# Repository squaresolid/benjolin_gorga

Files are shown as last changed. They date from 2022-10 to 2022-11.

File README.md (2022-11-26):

# benjolin_gorga
A tribute to Rob Hordijk (RIP)

As I was taking care of my wife at the hospital, I decided to redesign Forestcaver's Benjolin https://github.com/forestcaver/Benjolin
As I was finishing this, Rob Hordijk passed away and I would like to dedicate this to him.
The board come with several changes, which is: 
- 1206 components instead of 0603 which allows a much friendlier hand soldering
- DIP package for SSM2164 as in Indonesia it's pretty hard to find SMD components
- Gorga Graphics for Panel (Panel size is still as eurorack standard so no efficient cost production can be made)
- 100mm x 78mm circuit board redesign which allows a much cheaper PCB production.
- Optionable switch footprints, as the small switch is quite difficult to find in Indonesia
- Rearranged the layout a bit so all the knobs is on the right side

A eurorack version 1.6 of Rob Hordijk's Benjolin with 100mm x 78mm which significantly reduce the cost of printing PCB. The panel still on eurorack standard size though, so no cost reduction there. The panel design is enhanced with Batak's Gorga (Indonesian tribe from Sumatra) drawings.

All Kicad file provided is using Kicad 6

== Panel design ==
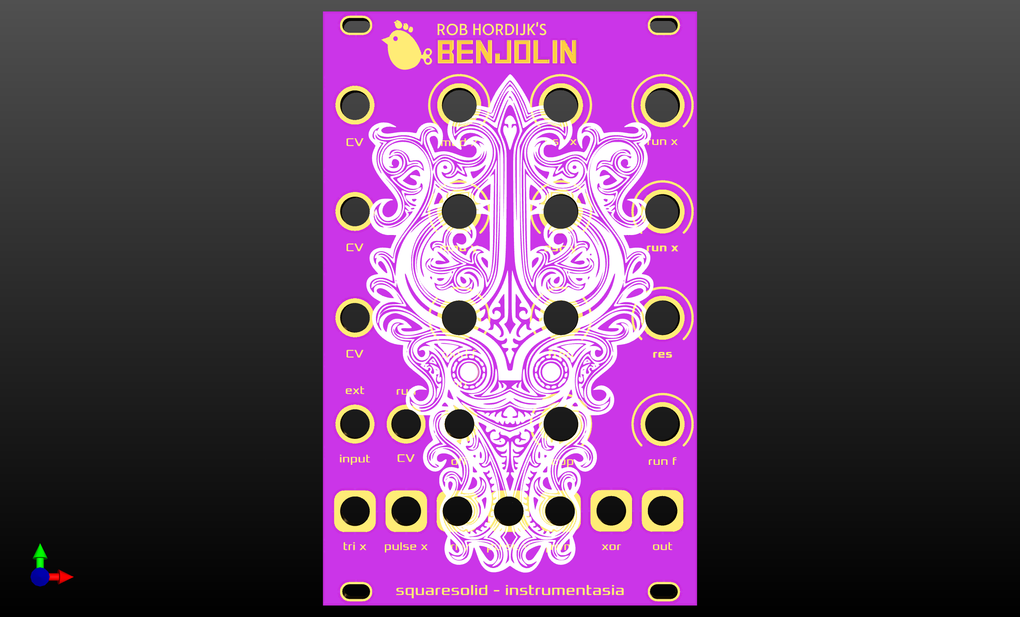
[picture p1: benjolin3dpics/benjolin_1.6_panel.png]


== PCB design ==
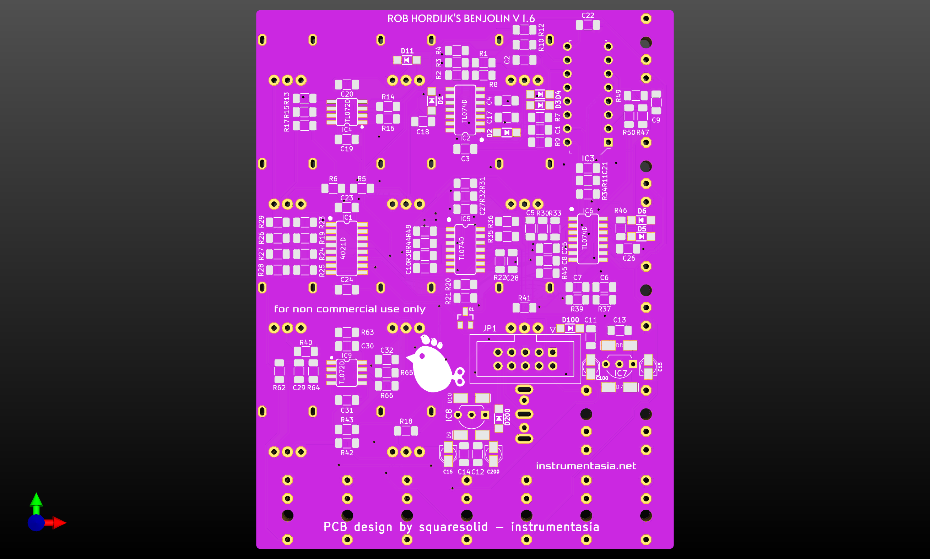
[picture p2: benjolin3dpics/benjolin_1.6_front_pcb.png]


== Build design ==
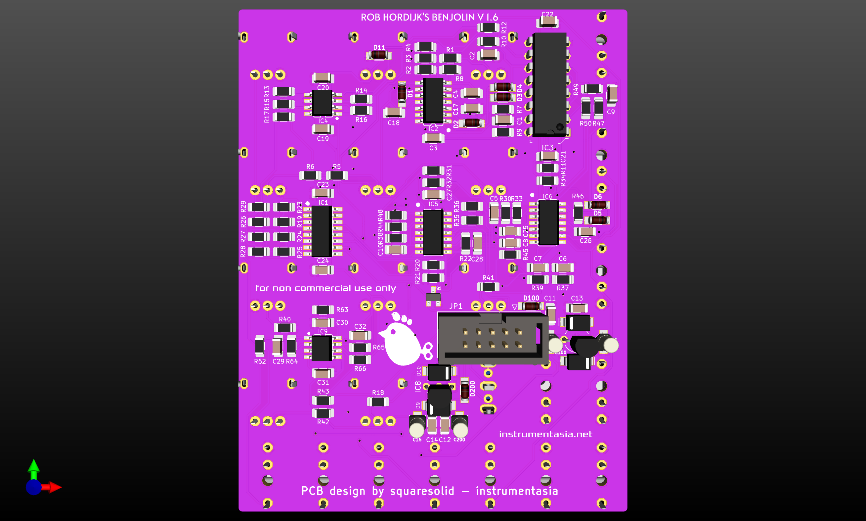
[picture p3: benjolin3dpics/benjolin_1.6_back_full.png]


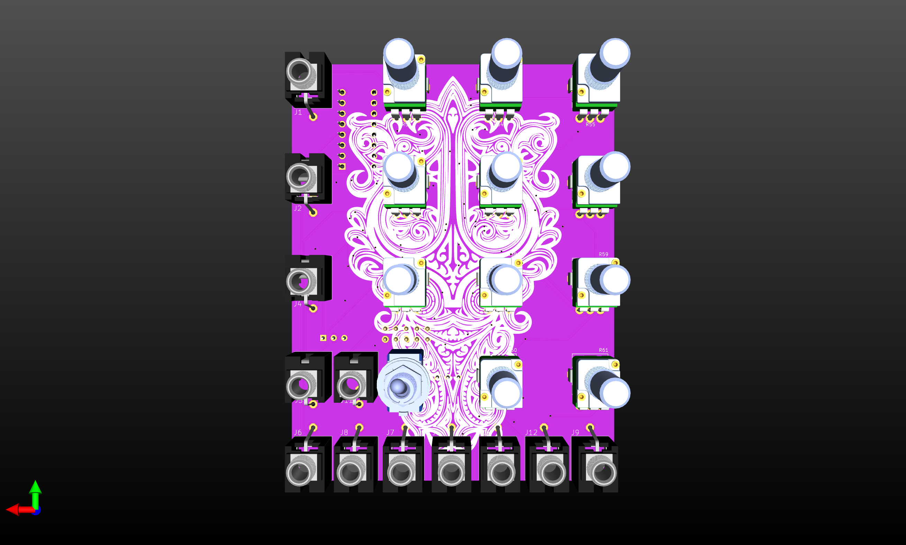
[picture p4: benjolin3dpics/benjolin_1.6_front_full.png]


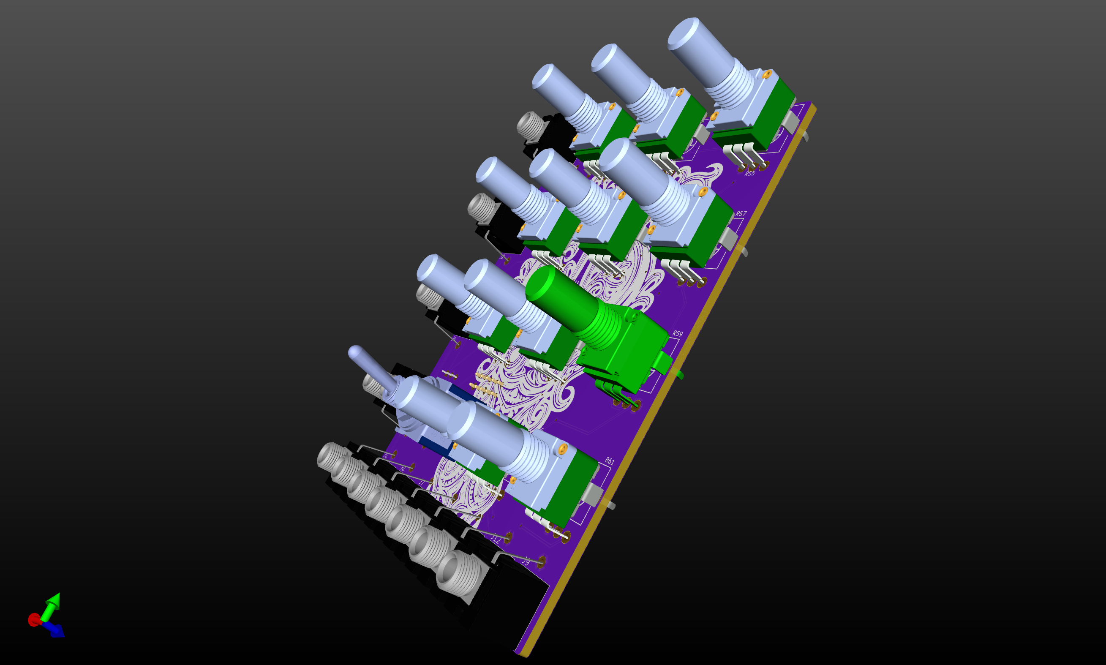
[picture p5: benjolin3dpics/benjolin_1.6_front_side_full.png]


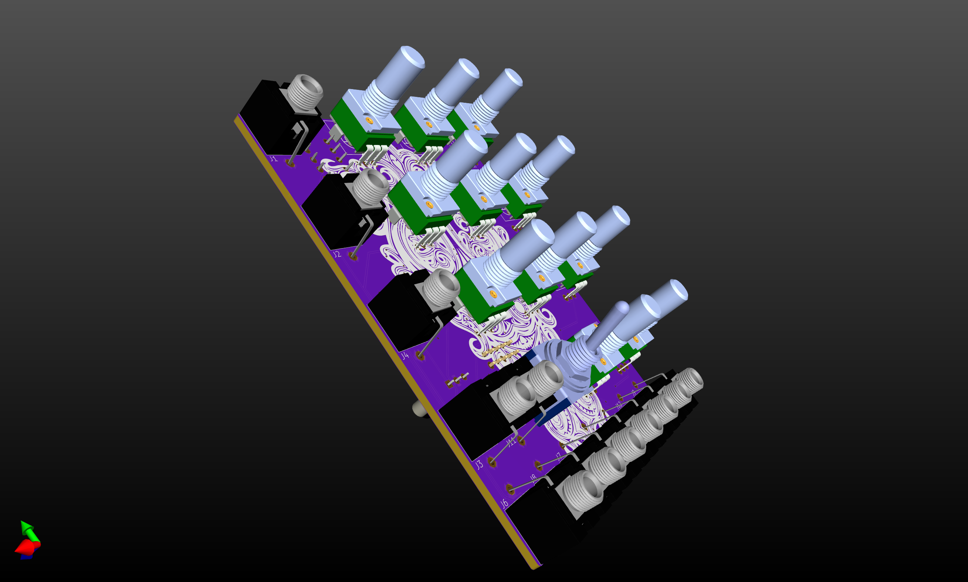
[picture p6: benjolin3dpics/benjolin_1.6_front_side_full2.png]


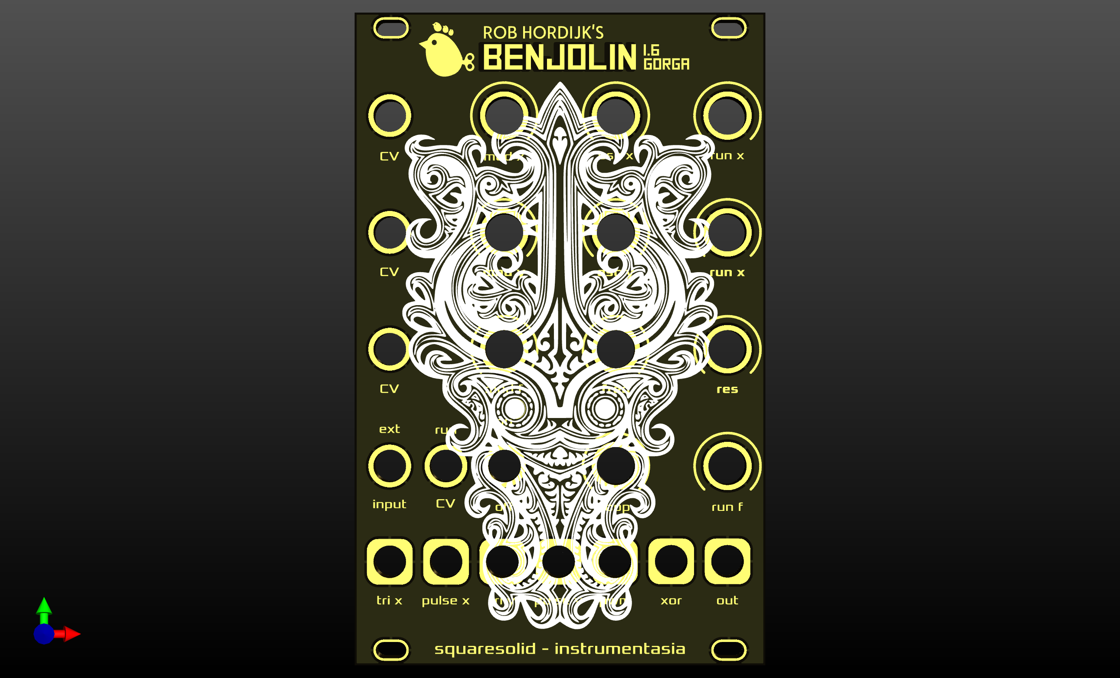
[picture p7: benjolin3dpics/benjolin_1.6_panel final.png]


== PCB production by PCBway [https://www.pcbway.com] ==
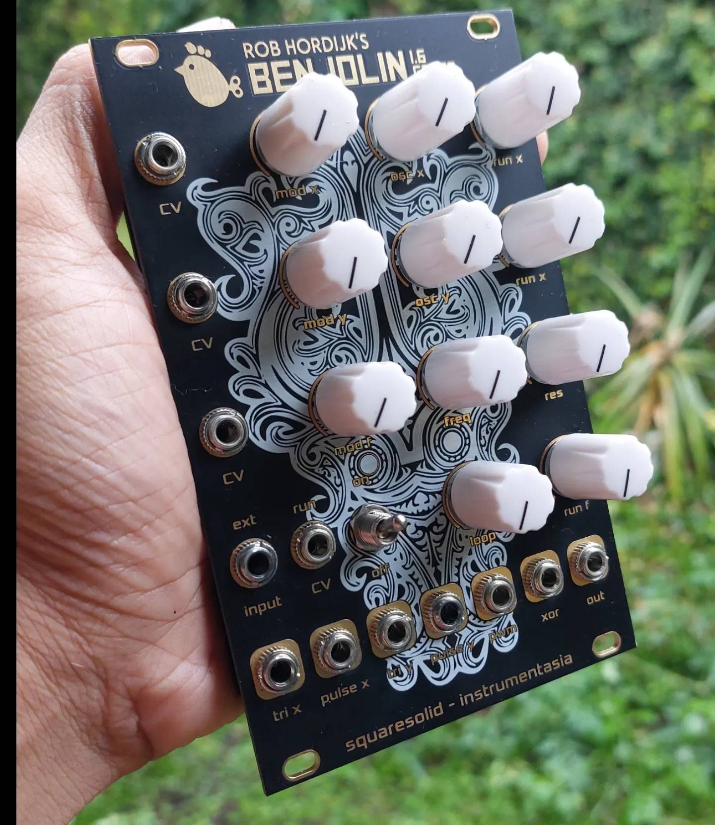
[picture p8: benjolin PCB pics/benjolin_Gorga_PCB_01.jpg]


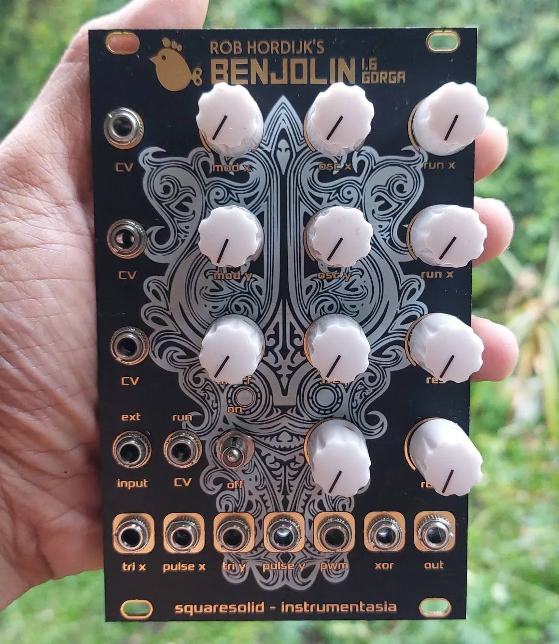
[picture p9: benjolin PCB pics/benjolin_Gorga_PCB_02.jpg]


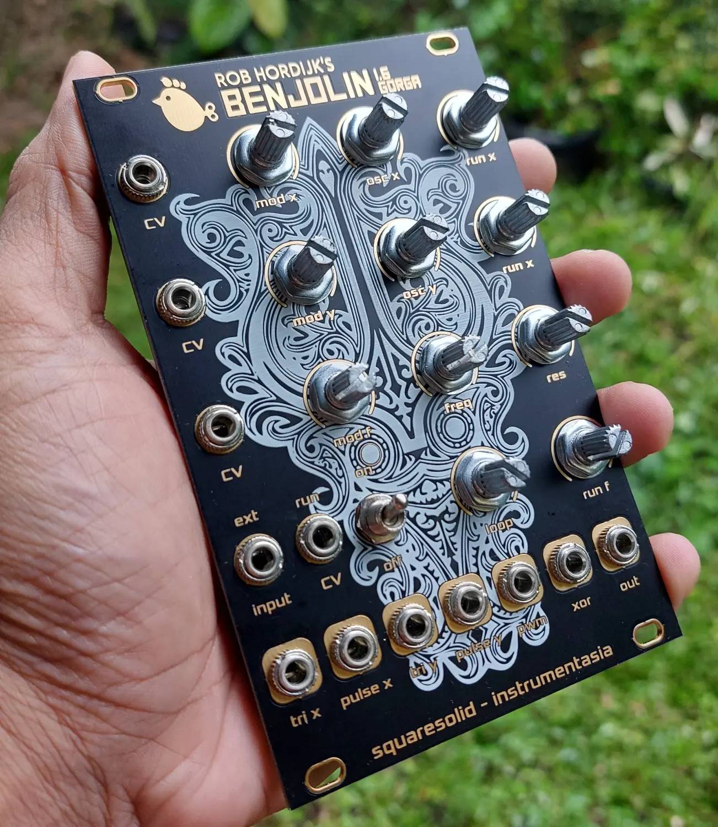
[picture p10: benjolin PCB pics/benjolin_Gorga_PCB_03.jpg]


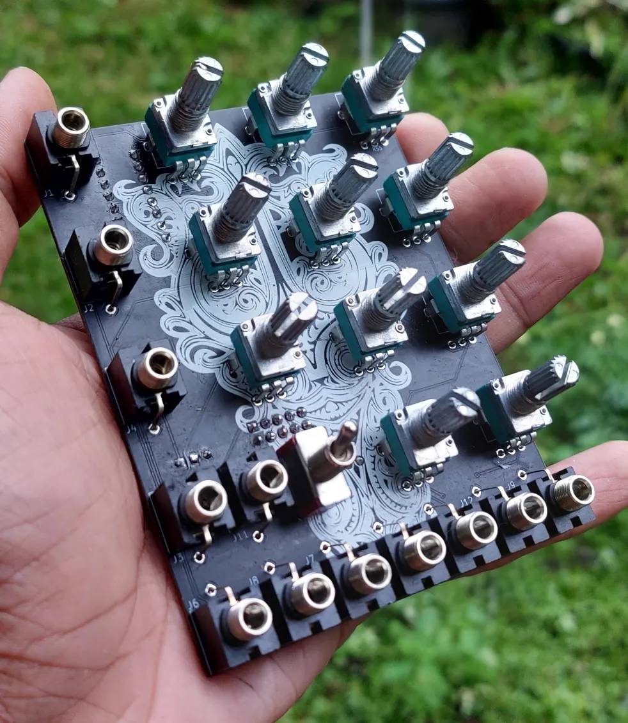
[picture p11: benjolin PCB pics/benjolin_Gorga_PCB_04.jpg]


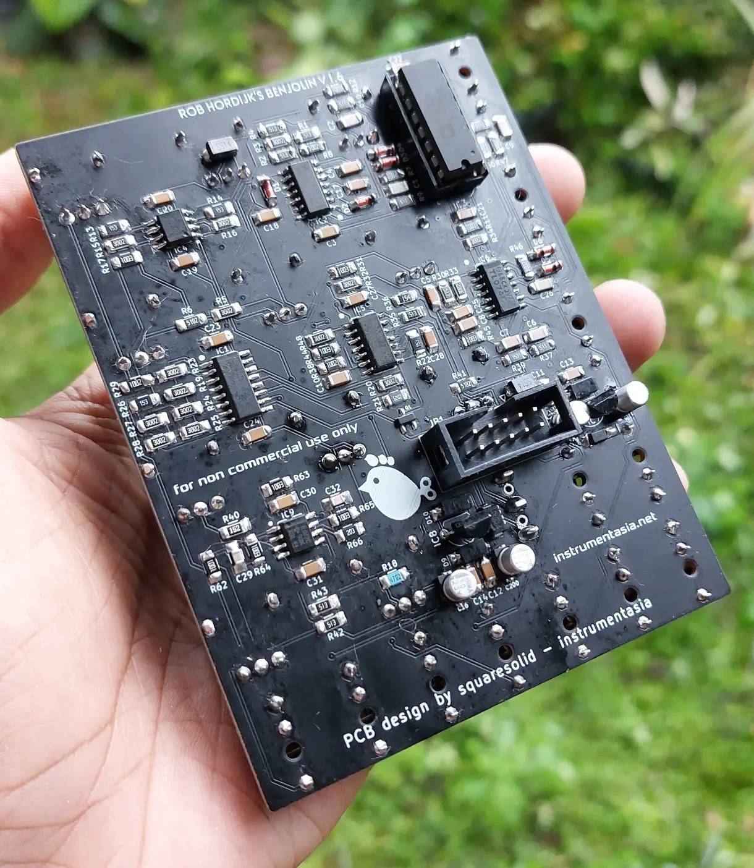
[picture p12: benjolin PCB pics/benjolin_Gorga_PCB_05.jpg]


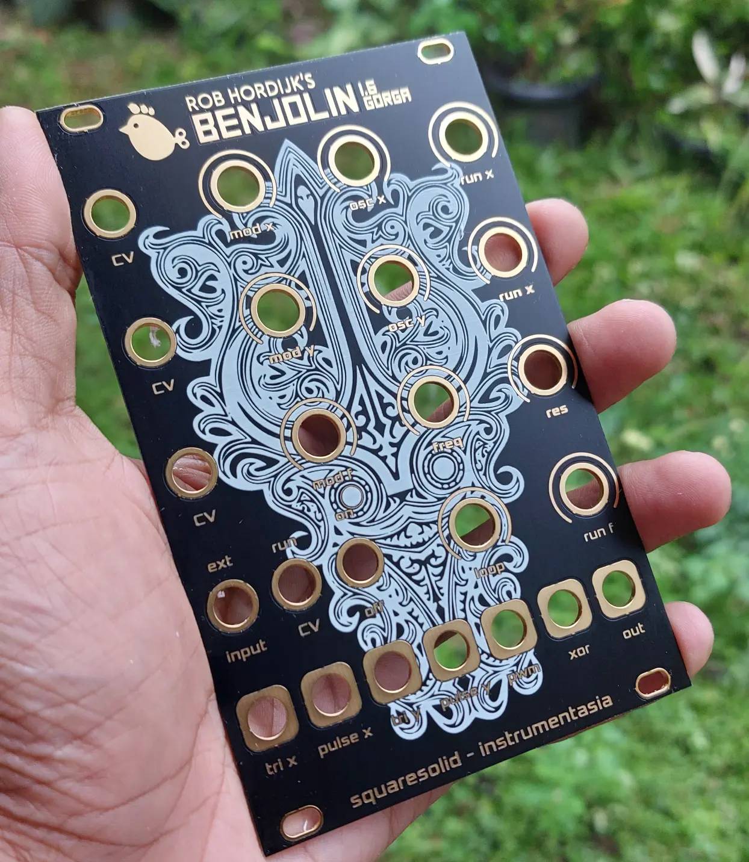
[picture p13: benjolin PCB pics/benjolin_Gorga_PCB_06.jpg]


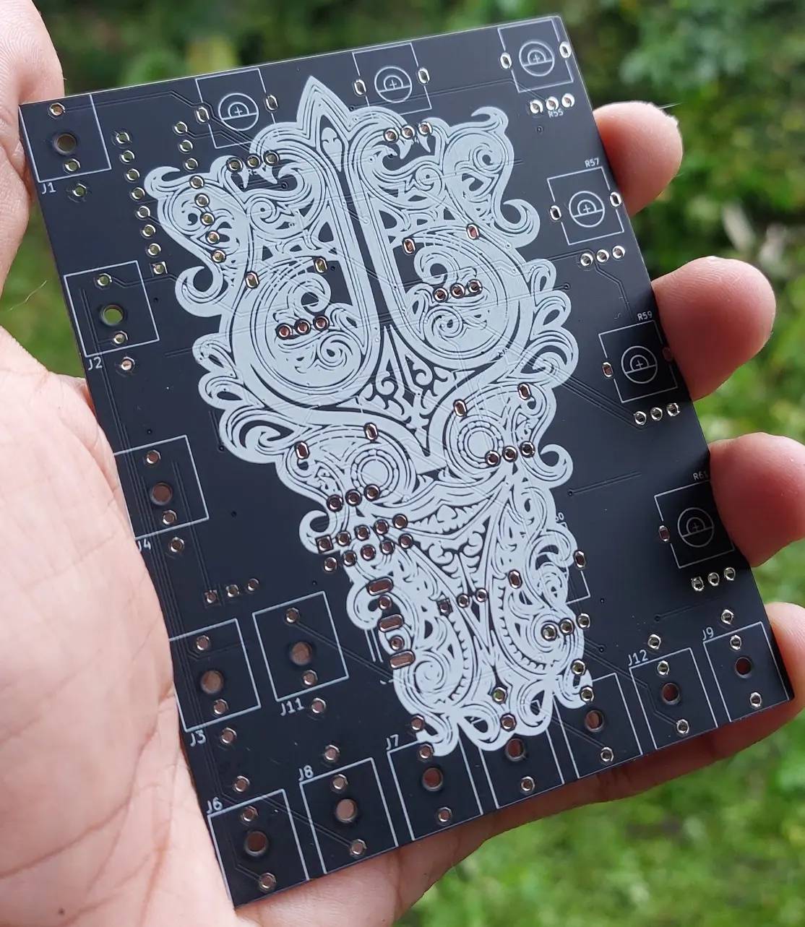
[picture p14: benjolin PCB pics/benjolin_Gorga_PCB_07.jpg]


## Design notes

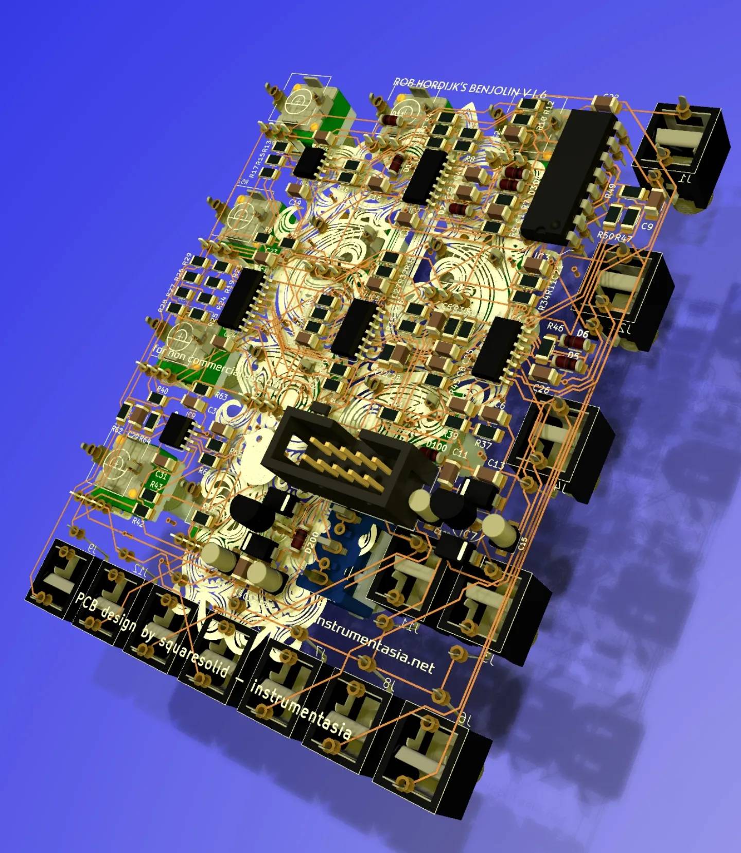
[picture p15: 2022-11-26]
benjolin PCB pics/benjolin_Gorga_PCB_09.jpg

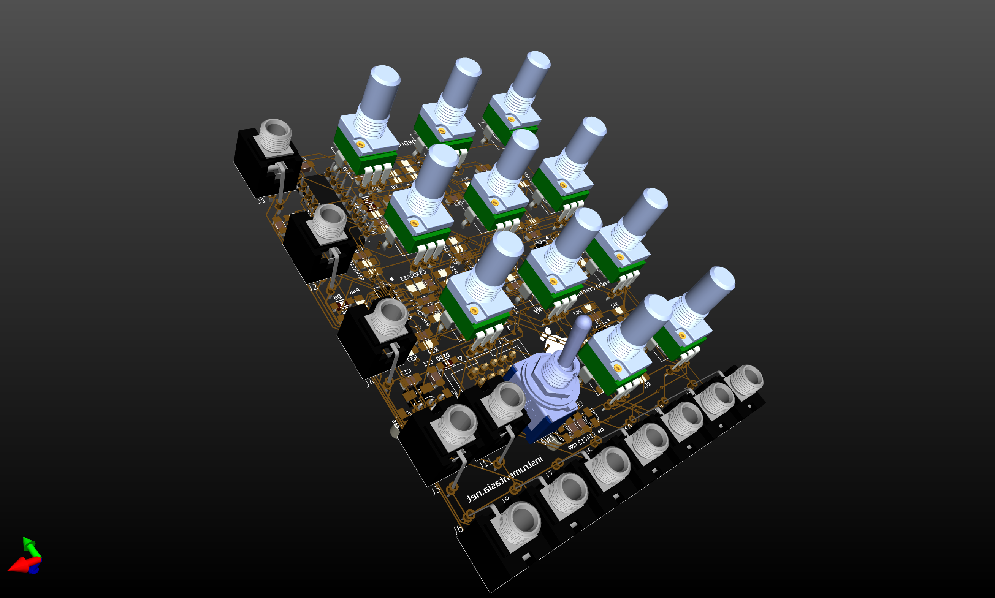
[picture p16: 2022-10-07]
benjolin3dpics/benjolin_1.6_front_wire_side2.png

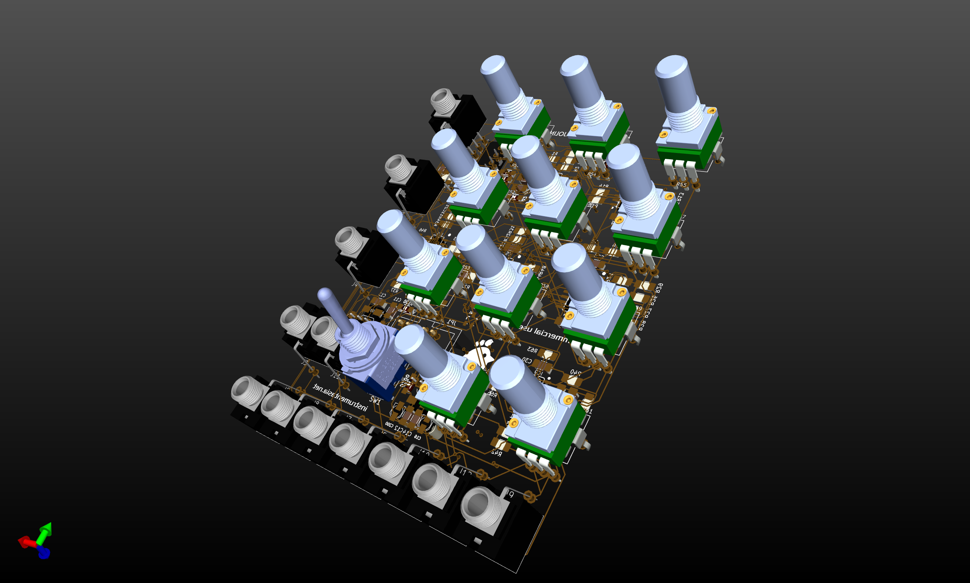
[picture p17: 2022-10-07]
benjolin3dpics/benjolin_1.6_front_wire_side.png

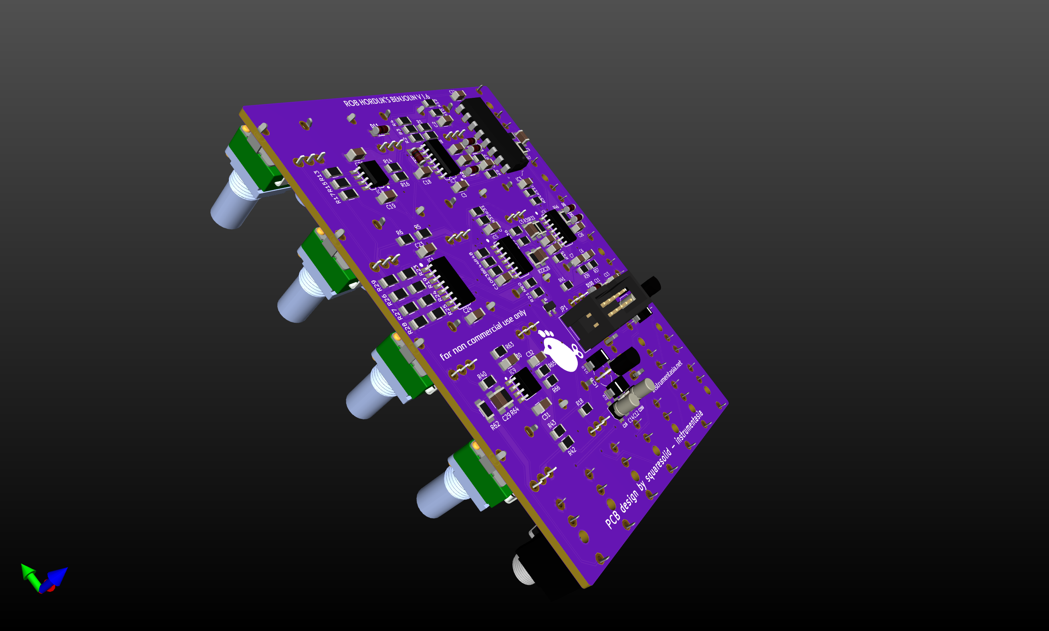
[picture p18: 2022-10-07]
benjolin3dpics/benjolin_1.6_back_side_full2.png

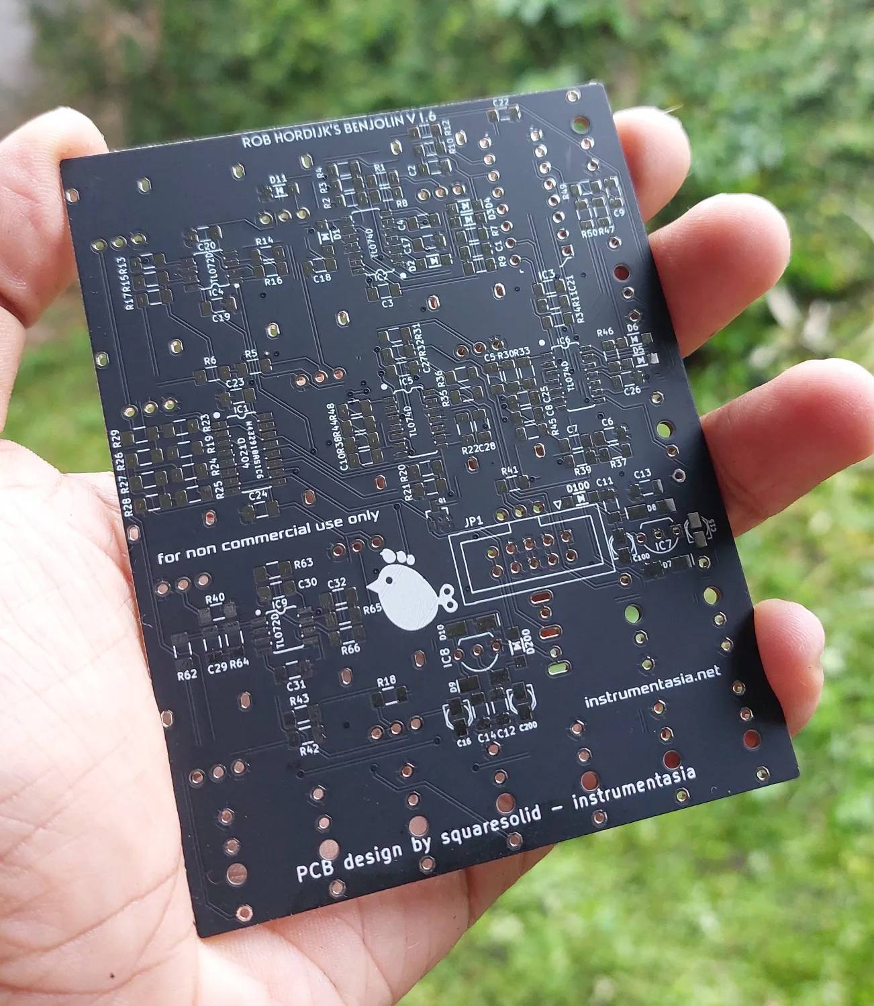
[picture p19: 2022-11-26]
benjolin PCB pics/benjolin_Gorga_PCB_08.jpg

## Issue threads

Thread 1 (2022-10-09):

Kicad files

KeLaiFu, 2022-10-09:
First of all, thanks for reworking this design, you did a great job and this was something I was playing around with in Kicad myself so I know it can be very time consuming.

Would it be possible for you to share the actual kicad files so I can add a few tweaks to my preference (mainly the spacing of the pots in relation to the right side of the panel)

Thanks again!

squaresolid, 2022-10-09:
Hey KeLaiFu!

Thanks for let me know. I was doing the Kicad with my wife's laptop at the Hospital, and I thought I uploaded all the files up on Github. It seems maybe the connections stopped or I forgot or whatever. Now it's there, have fun tweaking it and let me know if you're printing one, because I haven't. I will order it soon too! Thanks again!

Closed 2022-10-09.

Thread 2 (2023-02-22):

Power header upside down?

KeLaiFu, 2023-02-22:
I'm just checking my revision of your layout before I send it to jlc and unless I am misunderstanding it, isn't the power header upside down?
I checked your photos and the finished module has the header the same way as the PCB layout so now I am very confused.

KeLaiFu, 2023-02-22:
Ah, I see, I checked with the forestcaver layout after posting here and noticed he didn't add the keyed header so I guess it doesn't matter in his case. I edited the question about the LM, i was just being dumb and didn't notice the other one...
Thanks again!

Closed 2024-03-05.

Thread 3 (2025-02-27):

inconsistent kicad files

PipoPL, 2025-02-27:
Hello @squaresolid  !
Thanks for this layout !
I'm currently building it and I realized the kicad files on this repo are not consistent with the IBom and the pictures.
In the current kicad pcb the power connector is upside down and the markings for C7 and R39 are reversed too.  I see some of the markings are not in the same place than the pictures or the ibom either.

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

I just checked the gerber files in here and they correspond to the actual pcb file so **they also have those errors ! **

It would be good to have a note for all the people that used the current gerbers and will end up with those mistakes on the boards.

thx in advance for your attention !

PipoPL, 2025-02-27:
UPDATE:  finished the build. I tested briefly and everything seems to work. I have not used any external CVs yet or have not tried any cross modulations. The board I have corresponds to the current Kicad files and gerbers of this repo.

Changes:
 - R39 and C7 are swaped. This seems to be a mistake not on the schematic but the marking of the silkscreen.

Important:
- the position of the voltage regulators is correct and coherent with the way the power connector is on the pcb files.
- IC7 = 78L09
- IC8 = 79L09
- the power connector is in the correct orientation in this case. Pin 1 and 2 are -12v. Pin 9 and 10 are +12v

Closed 2025-06-12.

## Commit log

2022-10-07 Add files via upload
    Upload Benjolin Gorga Panel
    [benjolin_1.6_panel-B_Cu.gbr, benjolin_1.6_panel-B_Mask.gbr, benjolin_1.6_panel-B_Paste.gbr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]
2022-10-07 Add files via upload
    Add footprints
2022-10-07 Add files via upload
    Add Gerber Files
    [benjolin_1.6-B_Cu.gbr, benjolin_1.6-B_Fab.gbr, benjolin_1.6-B_Mask.gbr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]
2022-10-07 Add files via upload
    Add Panel Gerber
    [benjolin_1.6_panel-B_Cu.gbr, benjolin_1.6_panel-B_Mask.gbr, benjolin_1.6_panel-B_Paste.gbr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]
2022-10-07 Add files via upload
    Add Panel Kicad
2022-10-09 Add files via upload
    Main FIle
    [benjolin_1.6.kicad_sch, benjolin_1.6_2.kicad_sch, benjolin_1.6_3.kicad_sch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]
